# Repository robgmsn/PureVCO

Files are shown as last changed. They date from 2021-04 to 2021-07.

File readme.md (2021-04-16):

View this project on [CADLAB.io](https://cadlab.io/project/24199). 

DESIGN STATUS: Awaiting testing - Ready for beta testing.

VCO Updated to V3.1 14/04/21.

Mixer section changed from Average to Sum. Mix Out is now inversion of individual outs. Might be useful?
Resistor values around mixer section reduced to 10k, inline with low noise techniques.

To do:
Final test build

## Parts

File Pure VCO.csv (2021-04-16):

Library | Qty | Parts | Description | Value | Package | SORT
GMSN | 9 | 1V/OCT, LIN, MIX, PULSE, PWM_IN, SAW, SINE, SYNC, TRI | 3.5 mm Jack Socket | PJ301M-12 | PJ301M-12 | 8
GMSN | 14 | C1, C2, C5, C6, C9, C10, C11, C12, C15, C16, C18, C19, C20, C21 | Capacitor | 100nF | C0805 | 3
GMSN | 3 | C3, C4, C17 | Capacitor | 100pF | C0805 | 3
GMSN | 1 | C13 | Capacitor | 10nF | C0805 | 3
GMSN | 1 | C14 | Capacitor | 1nF | C0805 | 3
GMSN | 1 | C8 | Capacitor | 22pF | C0805 | 3
GMSN | 2 | D3, D4 | Diode | 1N914 | SOD-323F | 3.9
GMSN | 2 | D1, D2 | Diode | STTH102A | SMADIODE | 3.9
GMSN | 7 | IC1, IC2, IC3, IC4, IC5, IC6, IC7 | Dual Op Amp | TL072 | SO08 | 4.5
GMSN | 2 | CP1, CP2 | Electro Capacitor | 10uF | 153CLV-0505 | 3
GMSN | 1 | JP1 | Header 5x2 | HEADER2X5SHD | 2X5-SHROUDED | 7
GMSN | 1 | T1 | N Channel JFET | MMBFJ309 | N_CHN | 4
GMSN | 2 | TP1, TP2 | NPN Transistor Matched Pair | DMMT3904W-7-F | TRANS_PAIR | 4
GMSN | 1 | C7 | Poly Film Capacitor | 2.2nF | POLY_CAP | 7
GMSN | 1 | TR1 | Pot | 100R | TRIMMER_TH | 7
GMSN | 4 | TR2, TR3, TR4, TR5 | Pot | 100k | TRIMMER_TH | 7
GMSN | 4 | PULSE_MIX, SAW_MIX, SINE_MIX, TRI_MIX | Pot | B100k | POT_9MM_BLUE_KNOB | 8
GMSN | 2 | FM_LEVEL, PWM_LEVEL | Pot | B100k | POT_9MM_GREEN_KNOB | 8
GMSN | 1 | COARSE | Pot | B100k | POT_9MM_RED_KNOB | 8
GMSN | 1 | FINE | Pot | B100k | POT_9MM_RED_MXR_KNOB | 8
GMSN | 1 | PULSE_WIDTH | Pot | B100k | POT_9MM_YELLOW_KNOB | 8
GMSN | 1 | R47 | Resistor | 0R | R0805 | 2
GMSN | 4 | R3, R16, R30, R45 | Resistor | 100k | R0805 | 2
GMSN | 14 | R14, R20, R23, R28, R38, R40, R41, R43, R44, R48, R49, R50, R51, R52 | Resistor | 10k | R0805 | 2
GMSN | 1 | R9 | Resistor | 120k | R0805 | 2
GMSN | 1 | R1 | Resistor | 150k | R0805 | 2
GMSN | 2 | R26, R32 | Resistor | 19k1 | R0805 | 2
GMSN | 2 | R33, R35 | Resistor | 1k3 | R0805 | 2
GMSN | 2 | R21, R22 | Resistor | 1k5 | R0805 | 2
GMSN | 2 | R24, R25 | Resistor | 22k | R0805 | 2
GMSN | 1 | R31 | Resistor | 27k | R0805 | 2
GMSN | 2 | R4, R19 | Resistor | 2M | R0805 | 2
GMSN | 1 | R2 | Resistor | 2M2 | R0805 | 2
GMSN | 1 | TC1 | Resistor | 2k | 0207/8.5 | 2
GMSN | 5 | R27, R29, R34, R37, R42 | Resistor | 2k | R0805 | 2
GMSN | 1 | R18 | Resistor | 2k2 | R0805 | 2
GMSN | 1 | R6 | Resistor | 390R | R0805 | 2
GMSN | 2 | R10, R17 | Resistor | 39k | R0805 | 2
GMSN | 2 | R8, R36 | Resistor | 3k3 | R0805 | 2
GMSN | 1 | R39 | Resistor | 402R | R0805 | 2
GMSN | 1 | R46 | Resistor | 50k | R0805 | 2
GMSN | 1 | R5 | Resistor | 560k | R0805 | 2
GMSN | 1 | R15 | Resistor | 56k | R0805 | 2
GMSN | 1 | R13 | Resistor | 5k6 | R0805 | 2
GMSN | 1 | R11 | Resistor | 680R | R0805 | 2
GMSN | 1 | R7 | Resistor | 87k | R0805 | 2
GMSN | 1 | R12 | Resistor | 9k1 | R0805 | 2
GMSN | 1 | IC8 | Shunt Voltage Reference | LM4040A50IDBZT | SOT95P237X112-3N | 4

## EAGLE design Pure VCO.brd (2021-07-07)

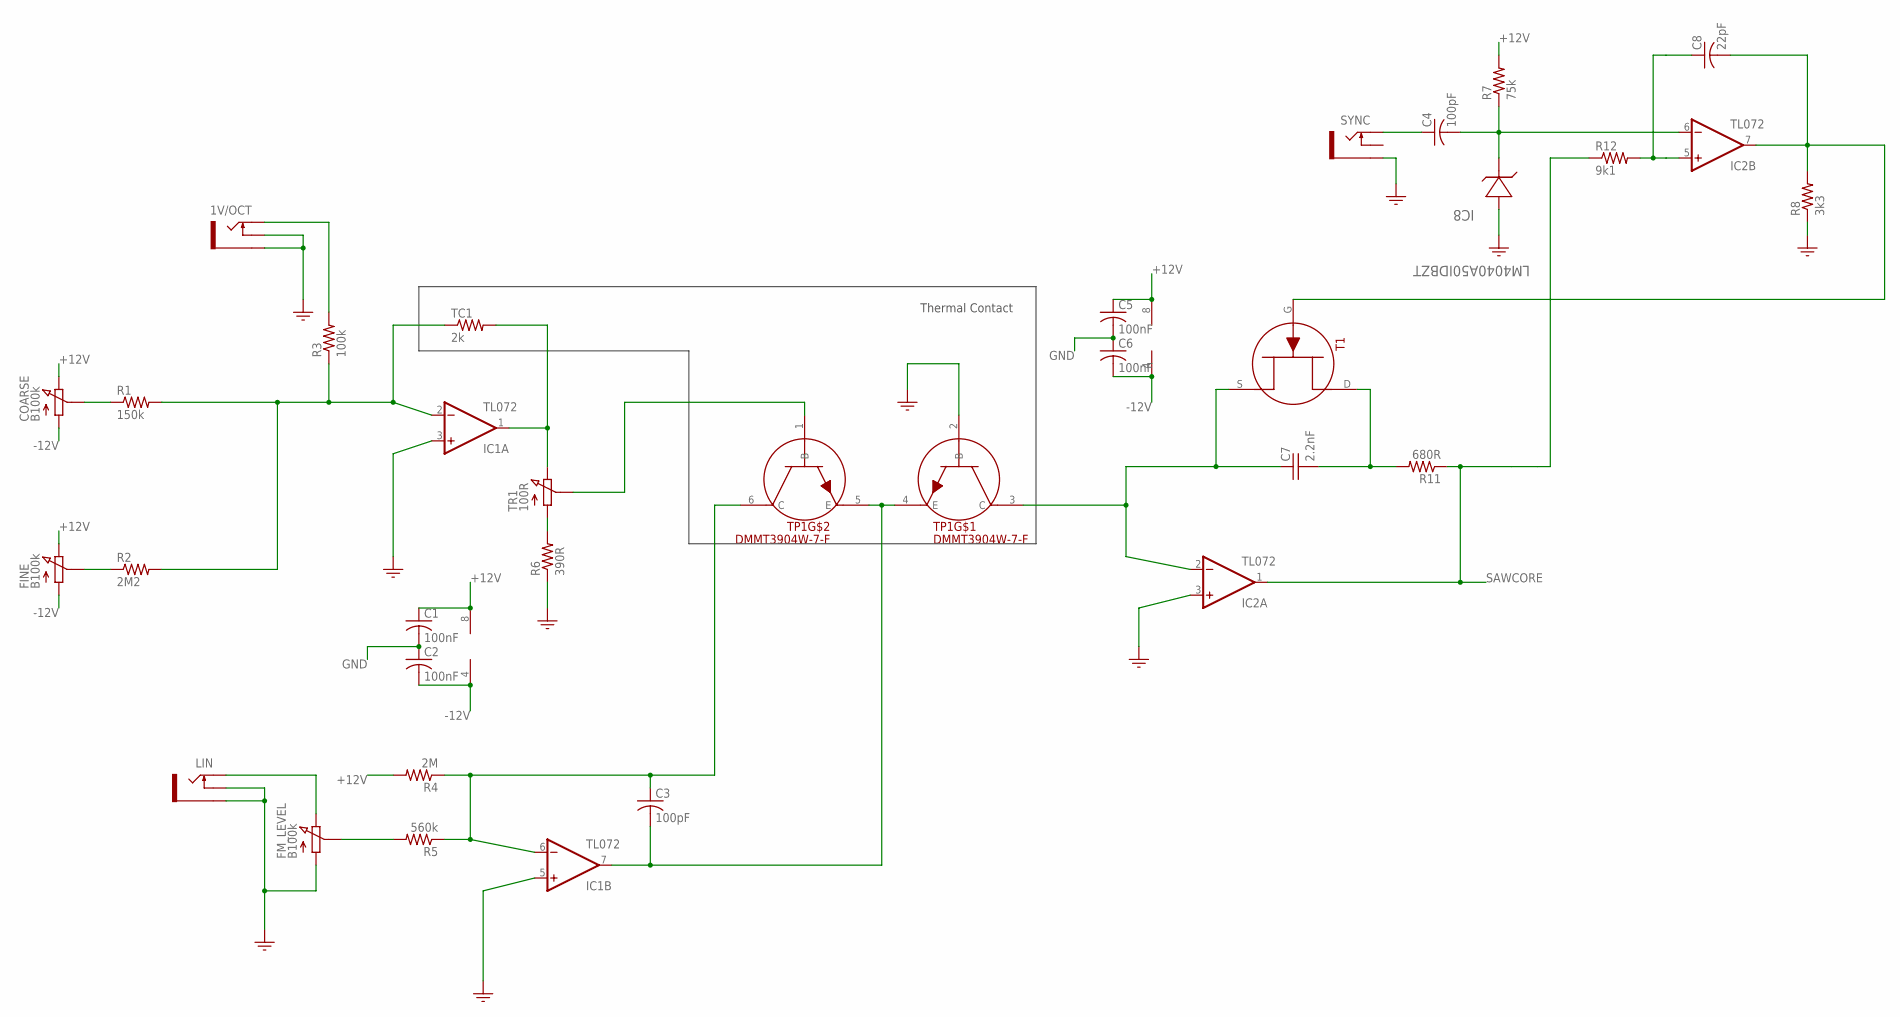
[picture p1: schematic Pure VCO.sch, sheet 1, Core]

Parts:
1V/OCT: PJ301M-12
C1, C2, C5, C6: 100nF; C0805
C3, C4: 100pF; C0805
C7: 2.2nF; POLY_CAP
C8: 22pF; C0805
COARSE: B100k; POT_9MM_RED_KNOB
FINE: B100k; POT_9MM_RED_MXR_KNOB
FM_LEVEL: B100k; POT_9MM_GREEN_KNOB
IC1, IC2: TL072; SO08
IC8: LM4040A50IDBZT; SOT95P237X112-3N
LIN: PJ301M-12
R1: 150k; R0805
R2: 2M2; R0805
R3: 100k; R0805
R4: 2M; R0805
R5: 560k; R0805
R6: 390R; R0805
R7: 75k; R0805
R8: 3k3; R0805
R11: 680R; R0805
R12: 9k1; R0805
SYNC: PJ301M-12
T1: MMBFJ309; N_CHN
TC1: 2k; 0207/8.5
TP1: DMMT3904W-7-F; TRANS_PAIR
TR1: 100R; TRIMMER_TH

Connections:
+12V: C1.1, C5.1, COARSE.P$3 (3), FINE.P$3 (3), IC1.8 (V+), IC2.8 (V+), R4.2, R7.2; also elsewhere on the board
-12V: C2.2, C6.2, COARSE.P$1 (1), FINE.P$1 (1), IC1.4 (V-), IC2.4 (V-); also elsewhere on the board
GND: 1V/OCT.GND (SLEEVE), 1V/OCT.NORM (SWITCH), C1.2, C2.1, C5.2, C6.1, FM_LEVEL.P$1 (1), IC1.3 (+IN), IC1.5 (+IN), IC2.3 (+IN), IC8.2 (ANODE), LIN.GND (SLEEVE), LIN.NORM (SWITCH), R6.1, R8.1, SYNC.GND (SLEEVE), TP1.2 (B); also elsewhere on the board
unnamed: COARSE.P$2 (2), R1.1
unnamed: IC1.2 (-IN), R1.2, R2.2, R3.1, TC1.1
unnamed: FINE.P$2 (2), R2.1
unnamed: IC1.1 (OUT), TC1.2, TR1.3
unnamed: R6.2, TR1.1
unnamed: 1V/OCT.TIP, R3.2
unnamed: TP1.1 (B), TR1.2
unnamed: C7.2 (-), R11.2, T1.D
unnamed: C3.1, IC1.6 (-IN), R4.1, R5.1, TP1.6 (C)
unnamed: C7.1 (+), IC2.2 (-IN), T1.S, TP1.3 (C)
unnamed: FM_LEVEL.P$3 (3), LIN.TIP
unnamed: C8.1, IC2.5 (+IN), R12.2
unnamed: FM_LEVEL.P$2 (2), R5.2
unnamed: C3.2, IC1.7 (OUT), TP1.4 (E), TP1.5 (E)
unnamed: C8.2, IC2.7 (OUT), R8.2, T1.G
unnamed: C4.1, SYNC.TIP
unnamed: C4.2, IC2.6 (-IN), IC8.1 (CATHODE), R7.1
SAWCORE: IC2.1 (OUT), R11.1, R12.1; also elsewhere on the board

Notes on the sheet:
Thermal Contact

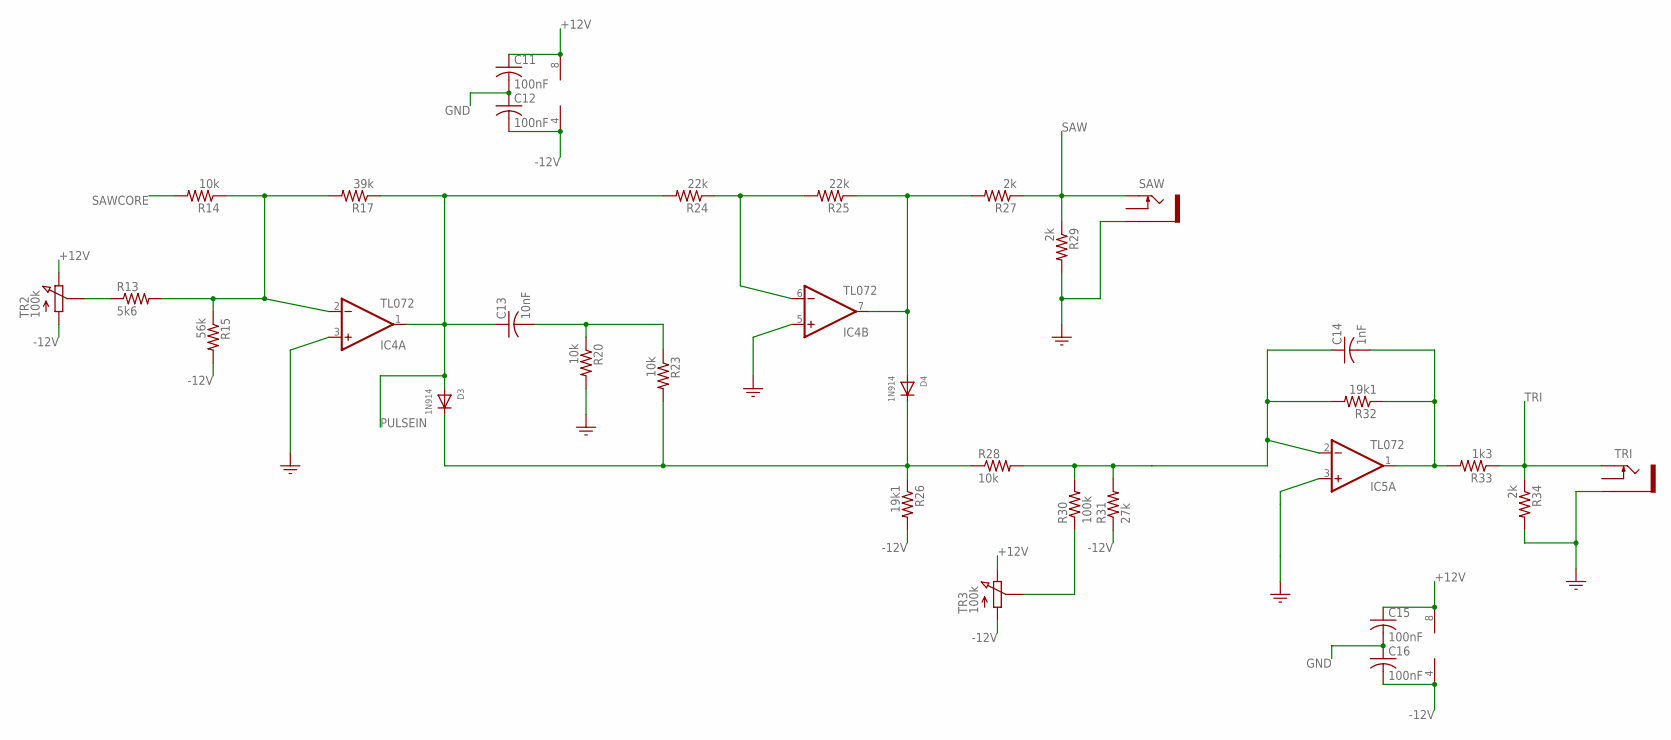
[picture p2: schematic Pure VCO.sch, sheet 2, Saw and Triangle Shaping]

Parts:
C11, C12, C15, C16: 100nF; C0805
C13: 10nF; C0805
C14: 1nF; C0805
D3, D4: 1N914; SOD-323F
IC4, IC5: TL072; SO08
R13: 5k6; R0805
R14, R20, R23, R28: 10k; R0805
R15: 56k; R0805
R17: 39k; R0805
R24, R25: 22k; R0805
R26, R32: 19k1; R0805
R27, R29, R34: 2k; R0805
R30: 100k; R0805
R31: 27k; R0805
R33: 1k3; R0805
SAW: PJ301M-12
TR2, TR3: 100k; TRIMMER_TH
TRI: PJ301M-12

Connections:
+12V: C11.1, C15.1, IC4.8 (V+), IC5.8 (V+), TR2.3, TR3.3; also elsewhere on the board
-12V: C12.2, C16.2, IC4.4 (V-), IC5.4 (V-), R15.2, R26.2, R31.1, TR2.1, TR3.1; also elsewhere on the board
GND: C11.2, C12.1, C15.2, C16.1, IC4.3 (+IN), IC4.5 (+IN), IC5.3 (+IN), R20.2, R29.2, R34.2, SAW.GND (SLEEVE), TRI.GND (SLEEVE); also elsewhere on the board
unnamed: R13.1, TR2.2
unnamed: IC4.2 (-IN), R13.2, R14.1, R15.1, R17.2
unnamed: C13.2, R20.1, R23.1
unnamed: R30.1, TR3.2
unnamed: IC4.6 (-IN), R24.1, R25.2
unnamed: D4.A, IC4.7 (OUT), R25.1, R27.2
unnamed: D3.C, D4.C, R23.2, R26.1, R28.1
unnamed: C14.1, IC5.2 (-IN), R28.2, R30.2, R31.2, R32.2
unnamed: C14.2, IC5.1 (OUT), R32.1, R33.2
PULSEIN: C13.1, D3.A, IC4.1 (OUT), R17.1, R24.2; also elsewhere on the board
SAW: R27.1, R29.1, SAW.TIP; also elsewhere on the board
SAWCORE: R14.2; also elsewhere on the board
TRI: R33.1, R34.1, TRI.TIP; also elsewhere on the board

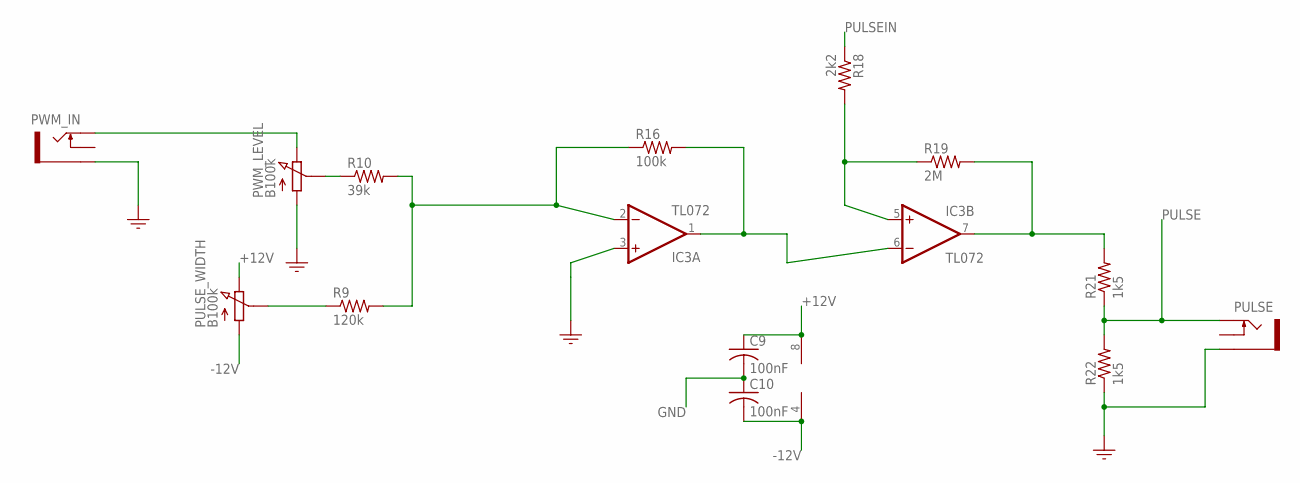
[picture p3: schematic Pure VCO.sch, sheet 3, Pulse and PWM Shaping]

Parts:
C9, C10: 100nF; C0805
IC3: TL072; SO08
PULSE: PJ301M-12
PULSE_WIDTH: B100k; POT_9MM_YELLOW_KNOB
PWM_IN: PJ301M-12
PWM_LEVEL: B100k; POT_9MM_GREEN_KNOB
R9: 120k; R0805
R10: 39k; R0805
R16: 100k; R0805
R18: 2k2; R0805
R19: 2M; R0805
R21, R22: 1k5; R0805

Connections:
+12V: C9.1, IC3.8 (V+), PULSE_WIDTH.P$3 (3); also elsewhere on the board
-12V: C10.2, IC3.4 (V-), PULSE_WIDTH.P$1 (1); also elsewhere on the board
GND: C9.2, C10.1, IC3.3 (+IN), PULSE.GND (SLEEVE), PWM_IN.GND (SLEEVE), PWM_LEVEL.P$1 (1), R22.1; also elsewhere on the board
unnamed: IC3.1 (OUT), IC3.6 (-IN), R16.2
unnamed: IC3.5 (+IN), R18.2, R19.1
unnamed: IC3.7 (OUT), R19.2, R21.2
unnamed: PULSE_WIDTH.P$2 (2), R9.1
unnamed: PWM_IN.TIP, PWM_LEVEL.P$3 (3)
unnamed: IC3.2 (-IN), R9.2, R10.2, R16.1
unnamed: PWM_LEVEL.P$2 (2), R10.1
PULSE: PULSE.TIP, R21.1, R22.2; also elsewhere on the board
PULSEIN: R18.1; also elsewhere on the board

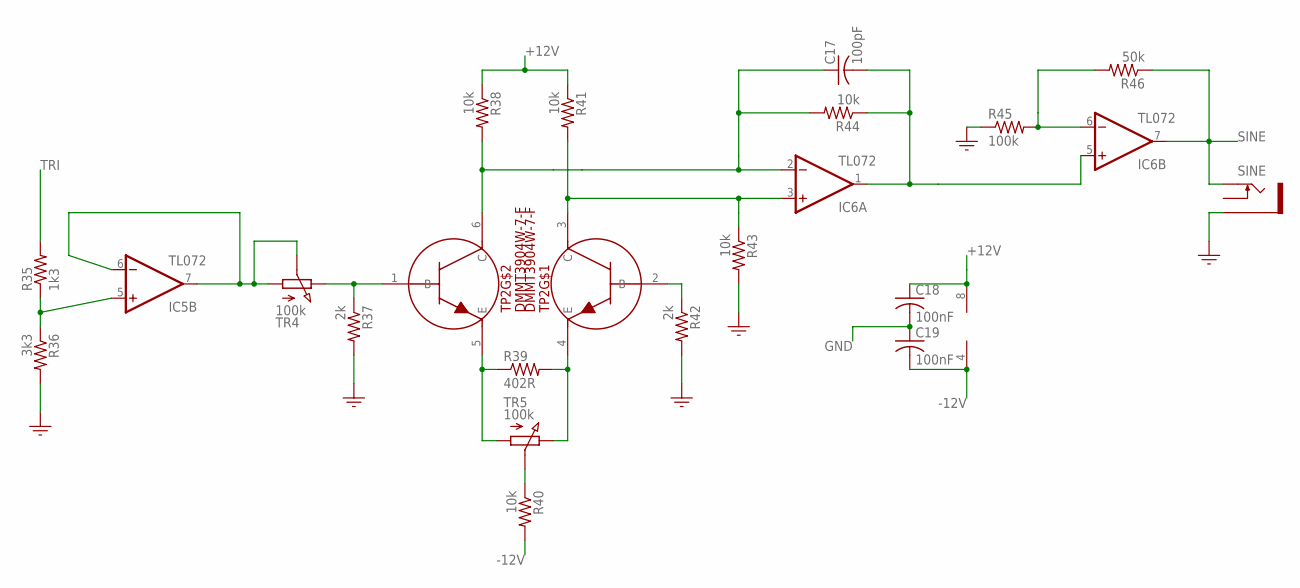
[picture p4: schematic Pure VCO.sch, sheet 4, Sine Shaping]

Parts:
C17: 100pF; C0805
C18, C19: 100nF; C0805
IC5, IC6: TL072; SO08
R35: 1k3; R0805
R36: 3k3; R0805
R37, R42: 2k; R0805
R38, R40, R41, R43, R44: 10k; R0805
R39: 402R; R0805
R45: 100k; R0805
R46: 50k; R0805
SINE: PJ301M-12
TP2: DMMT3904W-7-F; TRANS_PAIR
TR4, TR5: 100k; TRIMMER_TH

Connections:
+12V: C18.1, IC6.8 (V+), R38.1, R41.1; also elsewhere on the board
-12V: C19.2, IC6.4 (V-), R40.2; also elsewhere on the board
GND: C18.2, C19.1, R36.2, R37.2, R42.2, R43.2, R45.1, SINE.GND (SLEEVE); also elsewhere on the board
unnamed: C17.1, IC6.2 (-IN), R38.2, R44.2, TP2.6 (C)
unnamed: IC5.6 (-IN), IC5.7 (OUT), TR4.1, TR4.2
unnamed: R37.1, TP2.1 (B), TR4.3
unnamed: R39.1, TP2.5 (E), TR5.1
unnamed: R39.2, TP2.4 (E), TR5.3
unnamed: R40.1, TR5.2
unnamed: R42.1, TP2.2 (B)
unnamed: IC6.3 (+IN), R41.2, R43.1, TP2.3 (C)
unnamed: IC5.5 (+IN), R35.1, R36.1
unnamed: IC6.6 (-IN), R45.2, R46.2
SINE: IC6.7 (OUT), R46.1, SINE.TIP; also elsewhere on the board
SINE_PRE1: C17.2, IC6.1 (OUT), IC6.5 (+IN), R44.1
TRI: R35.2; also elsewhere on the board

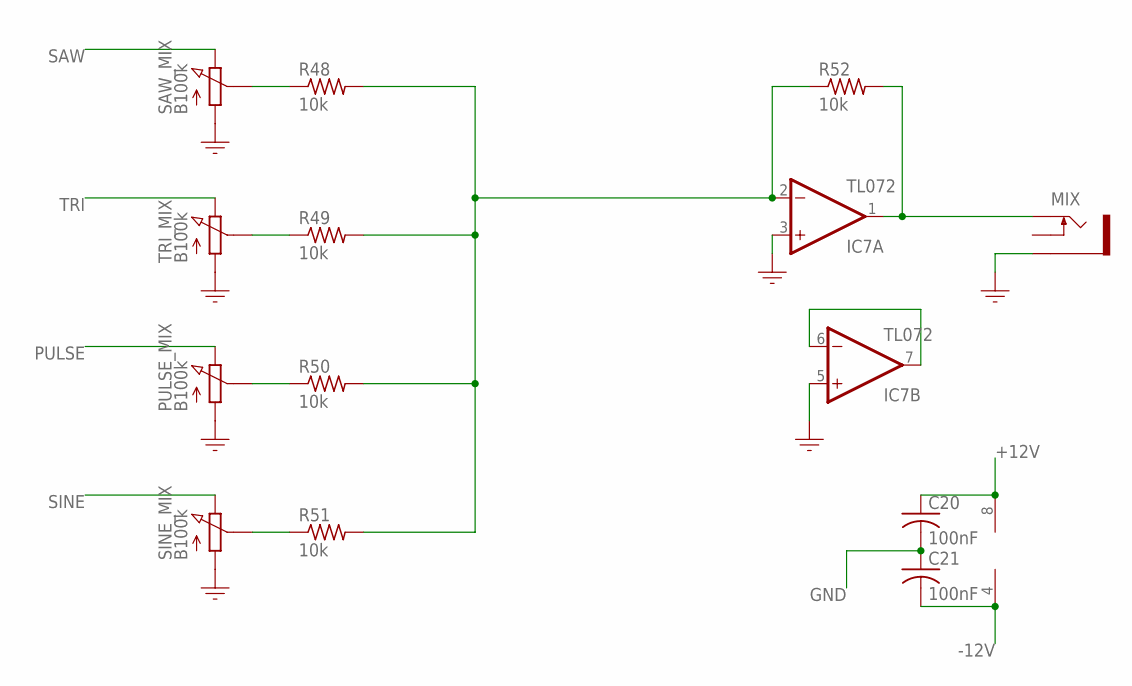
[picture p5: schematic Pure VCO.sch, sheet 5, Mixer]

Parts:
C20, C21: 100nF; C0805
IC7: TL072; SO08
MIX: PJ301M-12
PULSE_MIX: B100k; POT_9MM_BLUE_KNOB
R48, R49, R50, R51, R52: 10k; R0805
SAW_MIX: B100k; POT_9MM_BLUE_KNOB
SINE_MIX: B100k; POT_9MM_BLUE_KNOB
TRI_MIX: B100k; POT_9MM_BLUE_KNOB

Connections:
+12V: C20.1, IC7.8 (V+); also elsewhere on the board
-12V: C21.2, IC7.4 (V-); also elsewhere on the board
GND: C20.2, C21.1, IC7.3 (+IN), IC7.5 (+IN), MIX.GND (SLEEVE), PULSE_MIX.P$1 (1), SAW_MIX.P$1 (1), SINE_MIX.P$1 (1), TRI_MIX.P$1 (1); also elsewhere on the board
unnamed: IC7.6 (-IN), IC7.7 (OUT)
unnamed: R48.1, SAW_MIX.P$2 (2)
unnamed: R49.1, TRI_MIX.P$2 (2)
unnamed: PULSE_MIX.P$2 (2), R50.1
unnamed: R51.1, SINE_MIX.P$2 (2)
unnamed: IC7.2 (-IN), R48.2, R49.2, R50.2, R51.2, R52.1
unnamed: IC7.1 (OUT), MIX.TIP, R52.2
PULSE: PULSE_MIX.P$3 (3); also elsewhere on the board
SAW: SAW_MIX.P$3 (3); also elsewhere on the board
SINE: SINE_MIX.P$3 (3); also elsewhere on the board
TRI: TRI_MIX.P$3 (3); also elsewhere on the board

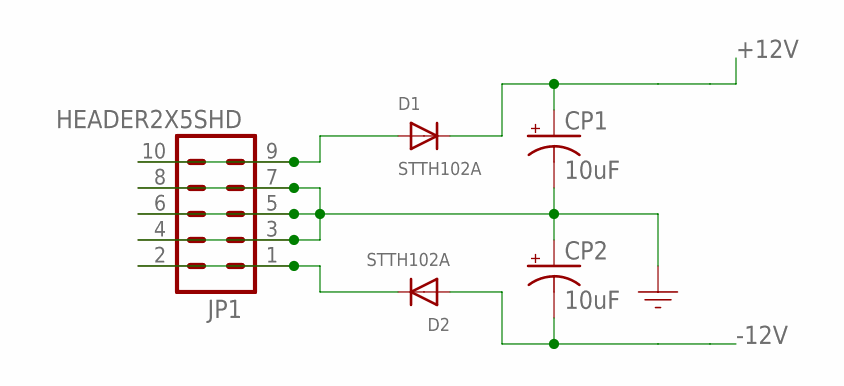
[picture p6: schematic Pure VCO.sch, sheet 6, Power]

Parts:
CP1, CP2: 10uF; 153CLV-0505
D1, D2: STTH102A; SMADIODE
JP1: HEADER2X5SHD; 2X5-SHROUDED

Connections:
+12V: CP1.+, D1.C; also elsewhere on the board
-12V: CP2.-, D2.A; also elsewhere on the board
GND: CP1.-, CP2.+, JP1.3, JP1.4, JP1.5, JP1.6, JP1.7, JP1.8; also elsewhere on the board
unnamed: D1.A, JP1.9, JP1.10
unnamed: D2.C, JP1.1, JP1.2

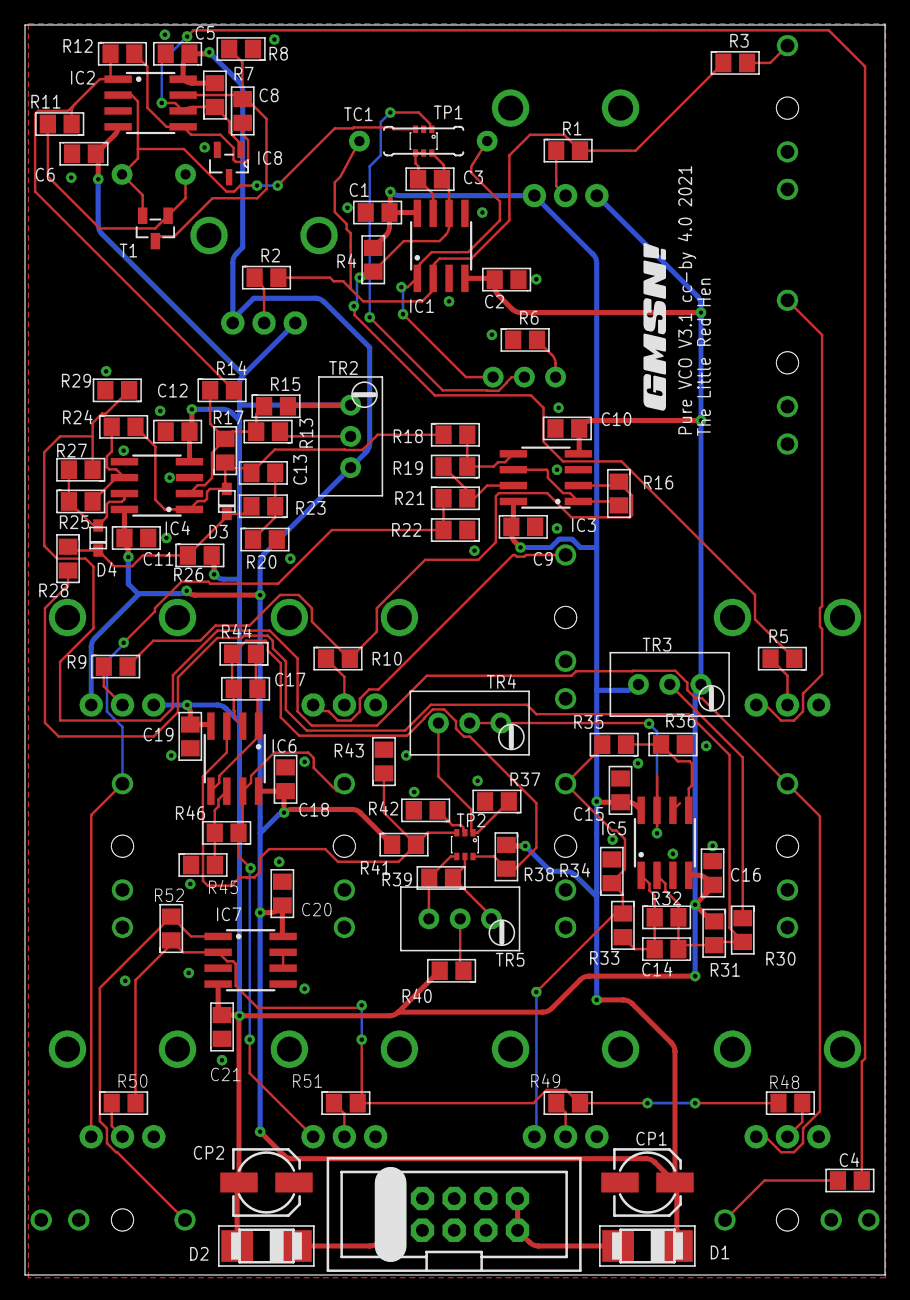
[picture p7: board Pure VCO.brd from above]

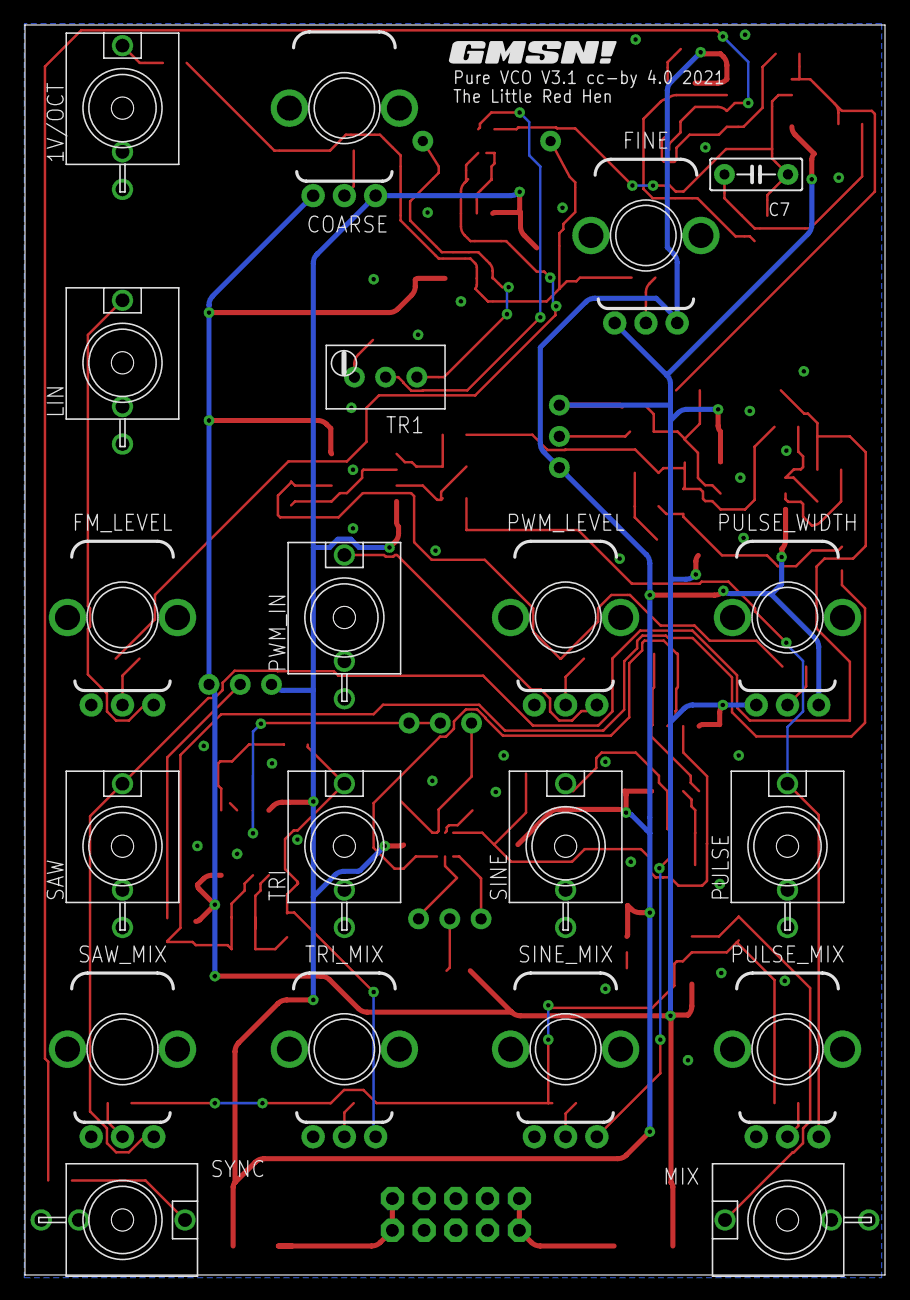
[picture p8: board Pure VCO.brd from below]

Board: 2 copper layers, 68.8 x 100.0 mm, 116 parts (21 on the bottom side), 62 nets.

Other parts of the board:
U$1, U$2: GMSN!_LOGO

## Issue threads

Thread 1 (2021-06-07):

IC8 = TP2?

KeLaiFu, 2021-06-07:
I've built the module from the 3.1 boards and can see something on the scope for saw and square but nothing audible.

Upon looking at the board for any faults I noticed What I thought was TP2 is marked IC8, to which there isn't an entry for on the BOM

Also, R7 requires a 87k resistor, which don't seem to exist, I put an 86.6k one in there.

robgmsn, 2021-06-07:
Support is only available to supporters of GMSN! via the forum: https://forum.gmsn.co.uk/
You can support GMSN! by buying PCBs and Panels via the webstore: https://gmsn.co.uk
A forum account can be created at checkout.

Closed 2021-06-07.

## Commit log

2021-04-16 VCO 2.0
    [Pure VCO.brd, Pure VCO.sch]
2021-04-16 VCO 2.1
    [Pure VCO.brd, Pure VCO.sch]
2021-04-16 VCO 2.3
    [Pure VCO.brd, Pure VCO.sch]
2021-04-16 VCO 3.0
    [Pure VCO.brd]
2021-04-16 VCO 3.1
    VCO Updated to V3.1 14/04/21.
    Mixer section changed from Average to Sum. Mix Out is now inversion of individual outs. Might be useful?
    Resistor values around mixer section reduced to 10k, inline with low noise techniques.
    [Pure VCO PCB Panel.brd, Pure VCO.brd, Pure VCO.csv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]

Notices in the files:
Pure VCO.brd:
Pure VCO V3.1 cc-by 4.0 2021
